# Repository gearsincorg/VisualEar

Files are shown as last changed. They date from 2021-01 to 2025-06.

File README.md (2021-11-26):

Visual Ear project
By Phil Malone
Phil.Malone@Mr-Phil.com
6/21/2021

https://hackaday.io/project/175944-the-visual-ear 
 
 This project is an experiment in audio perception.
 My goal was to produce a visual display that might help a deaf person experience sound.
 I got excited when I imagined what an orchestral performance might look like if each musician had such a display above their head.
 
 I started thinking about this project when I discovered that our Cochlea (the sensing part of our inner ear) does not just contain "hairs" that turn vibrations into electrical signals. 
 Instead, it is comprised of many micro structures (containing hairs) which are located along a tapered structure that filters out increasing frequencies of sound as you move into the structure.
 So, in reality, each successive cluster of hairs is detecting higher frequency components. 
 
 Thus the Cochlea does not convert vibrations into electrical impulses, but instead, it converts audio frequencies into electrical impulses.  It's acting as a spectrum analyzer.
 This is a marvelous piece of evolutionary adaption which removed the requirement of the brain to sense signals that were changing many thousands of times a second.
 
 This was quite a revelation to me, and it made me wonder if an external device that converted sound waves into similar frequency bands, and then displayed these bands using light (color and intensity) could be a crude substitute for a Cochlea.

 My first instinct was to think of a spectrum analyzer display that you might see on a high-end audio amplifier.
 There is nothing new about visual audio-spectrum displays, but I decided that it would be important to provide MUCH finer spectral resolution, while still maintaining near real-time response.

Display Specs:

- Display Bands:  104 Bands, spanning 43 Hz - 16744 Hz (8.5 Octaves, 12 LED's per octave)
- Intensity Range: Each Band is displayed with a secific color, and 255 intensity levels
- Display Update interval: 11.6 mSec (86 Hz)
- Audio to Visual Latency:  Max 13.5 mSec (11.6 mSec acquisition + 1.9 mSec for dual FFT & display)
- Visual Persistance:  Low Frequency (< 440 Hz) 185 mSec.  High Frequency (>= 440 Hz) 46 mSec.

 ** HOW IT WORKS 
 
 Note:  Program constants are referenced in this description as follows:  64 (CONSTANT_NAME)
 
 The Teensy audio library is used to sample the I2S digital microphone continuously at the standard 44100 Hz rate.  Successive Bursts of 128 samples are cataloged and saved as an array of Burst pointers.  This array holds 72 (NUM_BURSTS) Burst pointers.  Only 64 (BURSTS_PER_AUDIO) of these are being processed at any time.  The remaining 8 (EXTRA_BURSTS) are used to start capturing more audio while the current Packet of 64 Bursts is processed.  
 
 To cover the full 55-17,153 Hz spectrum, it’s necessary to aquire 8192 samples (64 Bursts of 128 samples).  But this would take 185 mSec to collect, so it’s not practical to wait for the full sample to be collected before updating the display.  
 
 To permit faster display updates, a sliding window is created to process the most recent 64 Bursts, every time a new set of 4 (BURSTS_PER_FFT_UPDATE) Bursts have been received.  This event occurs every 11.6 mSec, which becomes the update rate for the overall display (86 updates per second).
 
 A standard FFT (Fast Fourier Transform) is used to convert the Audio Packet (8196 Samples) into frequency buckets.  Initially, a single FFT was used to process the entire sample.  This transform could be performed in the available 11.6 mSec, but a high frequency sound spike would be spread over the entire 185 mS sample duration.  So a sudden sound would appear quickly, but it would persist on the display for the full 185 mSec.  This effectively limits the responsiveness of the system to rapid sounds like a drum roll.
 
 To accommodate BOTH slow low-frequency sounds, and rapid high-frequency sounds, the available Audio packet is processed by two separate FFTs.  Each optimized for a different frequency range.  The Low FFT is looking for sounds in the 55-880 Hz range.   The High FFT is looking for sounds in the 880-17,153 Hz range.  
 
 To capture and resolve low sounds, the Low FFT uses the entire Audio Packet, but it only processes every fourth sample.  This enables the FFT to work with a smaller input sample set of 2048, which still produces 1024 frequency bins of 5.4Hz width.
 
 To capture and resolve rapid high sounds, the High-FFT only uses the most recent quarter of the Audio Packet, but at the full 44.1 kHz sample rate.  This enables this FFT to also work with a smaller input sample set of 2048, but produces 1024 frequency bins of 21.5Hz width.  Since this FFT is only using a quarter of the sample history, short-pulse sounds only persist for a max of 46.4 mSec, which should be able to display a 10 Hz drum-roll.
 
CREDITS:

 > A lot of what I developed here was influenced strongly by Steve Marley https://github.com/s-marley/ESP32_FFT_VU
 
 > An explanation of the Spreadsheet used to determine the Band Bins is found here: https://www.youtube.com/watch?v=Mgh2WblO5_c
 
 > This project adapts the FFT library found here : https://github.com/kosme/arduinoFFT

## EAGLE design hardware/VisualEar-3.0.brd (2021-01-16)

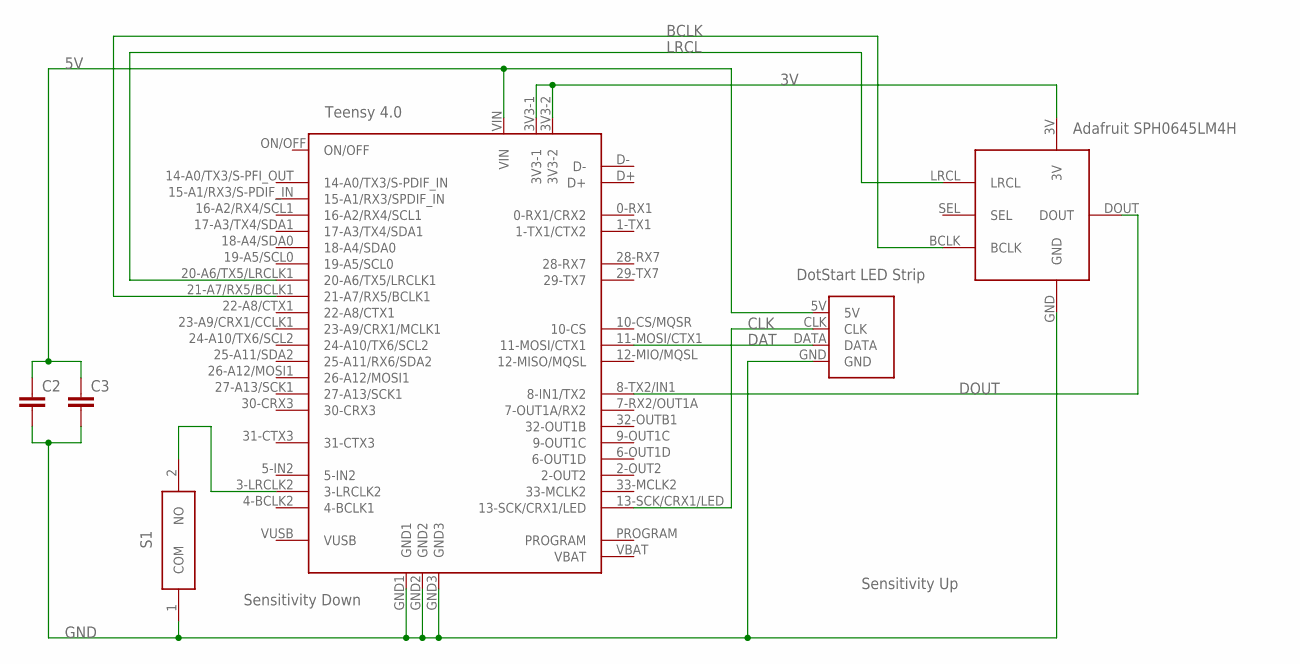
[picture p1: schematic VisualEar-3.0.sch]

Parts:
C2, C3: CAPPTH3; CAP-PTH-LARGE
S1: TACTILE-SWITCHTHRU-HOLE; CLICK-WEL
U$1: TEENSY40DIPPLUS5; TEENSY40-DIP+5
U$3: AF-I2S-MIC
U$4: LED-STRIP; LED_STRIP

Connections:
3V: U$1.3V3-1, U$1.3V3-2, U$3.3V
5V: C2.1, C3.1, U$1.VIN, U$4.5V
BCLK: U$1.21-A7/RX5/BCLK1, U$3.BCLK
CLK: U$1.13-SCK/CRX1/LED, U$4.CLK
DAT: U$1.11-MOSI/CTX1, U$4.DATA
DOUT: U$1.8-TX2/IN1 (8-IN1/TX2), U$3.DOUT
GND: C2.2, C3.2, S1.1 (COM), U$1.GND1, U$1.GND2, U$1.GND3, U$3.GND, U$4.GND
LRCL: U$1.20-A6/TX5/LRCLK1, U$3.LRCL
unnamed: S1.2 (NO), U$1.3-LRCLK2

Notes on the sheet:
DotStart LED Strip
Adafruit SPH0645LM4H
Teensy 4.0
Sensitivity Down
Sensitivity Up

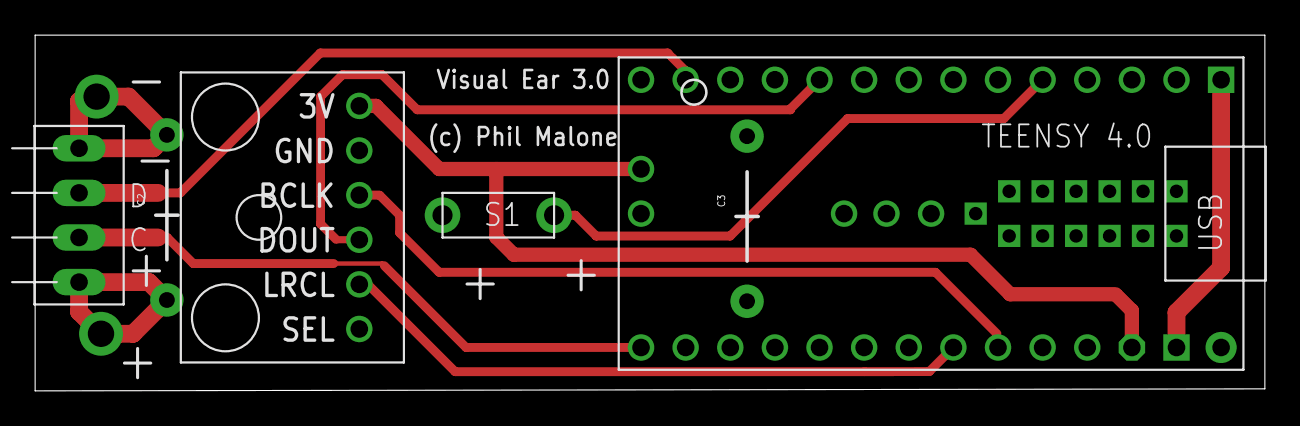
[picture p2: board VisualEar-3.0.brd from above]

Board: 2 copper layers, 70.0 x 20.2 mm, 6 parts (0 on the bottom side), 9 nets.

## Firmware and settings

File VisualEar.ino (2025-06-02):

/*
  Visual Ear
  Audio spectrum analyser
  LED strip display.
  For details see:  https://hackaday.io/project/175944-the-visual-ear
  Copyright (C) 2021-5 Philip Malone

  Display Modes:
  0 - Off
  1 - VU Mater
  2 - Specturm Analyser
  3 - Tone Detector
  4 - Fireworks
  5 - Ocean

  Version Date      Description
  2.0     2/2/2022  First release with 4 functions and 104 LEDs
  3.0     6/1/2025  Added Ocean mode with bubbles.
  
*/

#include  <Audio.h>
#include  <Wire.h>
#include  <SPI.h>
#include  <SerialFlash.h>
#include  <EEPROM.h>
#include  "audioAnalyzer.h"
#include  "devconf.h"
#include  "display.h"

#define  FASTLED_INTERNAL
#include "FastLED.h"

// Set project identification here
const char  Version[] = "Visual Ear. V4.0";
const char  Branch[]  = "Add Ocean";
const char  Description[]  = "104 Bands.  43Hz to 16744 Hz";
const char  Modes[]  = "(0) Off, (1) VU, (2) Spectrum, (3) Tone, (4) Fireworks, (5) Ocean";

// -- LED Display Constants
#define START_NOISE_FLOOR   60  // Frequency Bin Magnitudes below this value will not get summed into Bands. (Initial high value)  was 80
#define BASE_NOISE_FLOOR    40  // Frequency Bin Magnitudes below this value will not get summed into Bands. (Final minimumm value)

#define UI_HOLD_MS      3000
#define UI_STEP_MS       200
#define UI_BUTTON_PIN      3

const int myInput = AUDIO_INPUT_LINEIN;
//const int myInput = AUDIO_INPUT_MIC;

float     upGainAccumulator   = 0;
float     downGainAccumulator = 0;

// -- LED Display Data
uint32_t  bandValues[NUM_BANDS];
uint16_t  LO_bandBins[NUM_LO_BANDS + 1] = {13,14,15,16,17,18,20,21,22,23,25,26,28,29,31,33,35,37,39,41,44,46,49,52,55,58};
uint16_t  MD_bandBins[NUM_MD_BANDS + 1] = {29,31,33,35,37,39,41,44,46,49,52,55,58,62,66,70,74,78,83,88,93,98,104,110,117,124,131,139,147,156,165,175};
uint16_t  HI_bandBins[NUM_HI_BANDS + 1] = {25,27,28,30,32,33,35,37,40,42,45,47,50,53,56,60,63,67,71,75,79,84,89,94,100,106,112,119,126,134,142,150,159,168,178,189,200,212,225,238,252,267,283,300,318,337,357,378,400};

// Create the Audio components.  These should be created in the
AudioInputI2S          audioInput;     // audio shield: mic or line-in
AudioAnalyzeFFT        myFFT;
AudioAnalyzePeak       peak;          //xy=393,385

// Connect the live input
AudioConnection patchCord1(audioInput, 0, myFFT, 0);
AudioConnection patchCord2(audioInput, 0, peak, 0);

unsigned long startTime = millis();
unsigned long lastTime = millis();
unsigned long cycleTime = 0;

unsigned long buttonStart = 0;
bool          adjusting   = false;
bool          UIHolding = false;      
bool          UIButton  = false;      
bool          lastUIButton  = false;      

int           activeBands = 0;

// Non Volatile values
short         gainNumber  = 0;

// ==================================================================================================

void setup() {
  Serial.begin(500000); 

  pinMode(UI_BUTTON_PIN, INPUT_PULLUP);

  // Audio connections require memory to work.  For more
  AudioMemory(NUM_BURSTS);

  // read NV Ram
  setDisplayMode( EEPROM.read(MODE_ADDRESS));
  setGain(EEPROM.read(GAIN_ADDRESS));
  Serial.println(Version);
  Serial.println(Branch);
  Serial.println(Description);
  Serial.println(Modes);
  delay(100);

  initDisplay();
}

void loop() {
  // check the button and see if we have a change
  runUI();

  if (getDisplayMode() == 1) {       
    if (peak.available()){
      updateVuDisplay(peak.readPeakToPeak());
    }
  } else {       
    if (myFFT.available()) {
      // each time new FFT data is available update the diplay
      startTime = millis();
      cycleTime = startTime - lastTime;
      lastTime = startTime;
  
      fillBands();
      updateDisplay(bandValues);
      runAGC();
    }
  }
}

// ==================================================================================================

void  runUI() {
  
  // debounce
  if (pressElapsed() > 100) {
    UIButton = !digitalRead(UI_BUTTON_PIN);

    //  Just Pressed, start the hold timer
    if (UIButton && !lastUIButton) {
      pressReset();
    }

    // Look for button release.  Bump mode
    if (!UIButton && lastUIButton) {
      if (!UIHolding) {
        bumpMode();
      }
    }

    lastUIButton = UIButton;
  }
}

long  pressElapsed() {
  return millis() - buttonStart;
}

void  pressReset() {
  buttonStart = millis() ;
}

void  runAGC(){
  // Automatic Gain Control
    // Automatically control the gain to keep a reasonable quantity of active frequency buckets
  
  float OCR = (float)activeBands / (float)NUM_BANDS;
  
  /*
  Serial.print("AB ");
  Serial.print(activeBands);
  Serial.print(", GN ");
  Serial.println(gainNumber);
  */

  if (OCR < lowTrip) {
    upGainAccumulator += 0.01;
  } else if (OCR > highTrip) {
    upGainAccumulator -= 0.04;
  }

  if (upGainAccumulator > 1.0) {
    bumpGain(1);
    upGainAccumulator = 0.0;
  } else if (upGainAccumulator < -1.0) {
    bumpGain(-1);
    upGainAccumulator = 0.0;
  }

  /*  
  Serial.print("AGC OLC ");
  Serial.print(OLC);
  Serial.print(", OCR ");
  Serial.print(OCR);
  Serial.print(", UA ");
  Serial.print(upGainAccumulator);
  Serial.print(", Gain Number ");
  Serial.println(gainNumber);
  */
}

void  bumpGain(int step ) {
  buttonStart = millis();
  setGain(gainNumber + step);  
  pressReset();
}

void  bumpMode() {
  buttonStart = millis();
  EEPROM.write(MODE_ADDRESS, switchDisplayMode());
  initDisplay();  
}

// save the current selected gain value (which LED) and calculate Amplitude divide factor
int  setGain(short newgain) {
double        gainScale;

  if (newgain < MIN_GAIN_NUM)
    newgain = MIN_GAIN_NUM;
  else if (newgain > MAX_GAIN_NUM)
    newgain = MAX_GAIN_NUM;

  gainNumber = newgain;
  EEPROM.write(GAIN_ADDRESS, gainNumber);

  gainScale  = minScale * pow(gainSlope, gainNumber);
  myFFT.setInputScale(gainScale);

  /*
  Serial.print("Gain # ");
  Serial.print(gainNumber);
  Serial.print(" Gain ");
  Serial.println(gainScale * 100);
  */

  return gainNumber;
}

// ==================================================================================================

// Group Frequency Bins into Band Buckets based on the maximum nun number for each band
// Each band covers more bind because bins are linear and bands are logorithmic.
void  fillBands (void){
  uint32_t  noiseFloor;  
  uint8_t   band;   

  //  zero out all the LED band magnitudes.
  memset(bandValues, 0, sizeof(bandValues));

  // Cycle through each of the LED bands.  Set initial noise threshold high and drop down.
  noiseFloor = START_NOISE_FLOOR;
  band = 0;
  activeBands = 0;
    
  for (int b = 0; b < NUM_LO_BANDS; b++, band++){
    // Accumulate freq values from all bins that match this LED band,
    bandValues[band] = (uint32_t)myFFT.read(0, LO_bandBins[b], LO_bandBins[b+1], noiseFloor);
    if (bandValues[band] > 2)
      activeBands++;

    // Adjust Noise Floor
    if (noiseFloor > BASE_NOISE_FLOOR) {
      noiseFloor = 97 * noiseFloor / 100;  // equiv 0.97 factor.
    }
  }

  for (int b = 0; b < NUM_MD_BANDS; b++, band++){
    // Accumulate freq values from all bins that match this LED band,
    bandValues[band] = (uint32_t)myFFT.read(1, MD_bandBins[b], MD_bandBins[b+1], noiseFloor);
    if (bandValues[band] > 2)
      activeBands++;

    // Adjust Noise Floor
    if (noiseFloor > BASE_NOISE_FLOOR) {
      noiseFloor = 97 * noiseFloor / 100;  // equiv 0.97 factor.
    }
  }

  for (int b = 0; b < NUM_HI_BANDS; b++, band++){
    // Accumulate freq values from all bins that match this LED band,
    bandValues[band] = (uint32_t)myFFT.read(2, HI_bandBins[b], HI_bandBins[b+1], noiseFloor);
    if (bandValues[band] > 2)
      activeBands++;

    // Adjust Noise Floor
    if (noiseFloor > BASE_NOISE_FLOOR) {
      noiseFloor = 95 * noiseFloor / 100;  // equiv 0.95 factor.
    }
  }

}

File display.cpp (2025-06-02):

/*


*/

#include <Arduino.h>
#include "arm_math.h"
#include "devconf.h"
#include "display.h"

#define  FASTLED_INTERNAL
#include "FastLED.h"

// ======================================================================================================

CRGB      leds[NUM_LEDS];

float     hueStep;
int       numBands;
int       nextBall = 0;
uint32_t  lastMoveMs = 0;

float     pos[MAX_BALLS];
float     vel[MAX_BALLS];
uint8_t   band[MAX_BALLS];

uint8_t   numBalls[NUM_BANDS];
short     displayMode; 
uint32_t  modeChangeRelease = 0;

double    gainSlope = 1.0;
double    minScale  = 0.0;
double    lowTrip   = 0;
double    highTrip  = 1;

int       orangeLED;
int       redLED;

double  peakFilter = 0;
double  levelFilter = 0;

// ======================================================================================================
// Generic Display Functions
// ======================================================================================================
void  setDisplayMode(short  mode) {
  displayMode = mode;    
}

short  getDisplayMode() {
  return(displayMode);    
}

short  switchDisplayMode() {
  displayMode = (short)((displayMode + 1 ) % NUM_MODES);
  modeChangeRelease = millis() + MODE_CHANGE_PAUSE;
  showMode();
  return (displayMode);
}

void  initDisplay(){

  delay(250);      // sanity check delay
  FastLED.addLeds<APA102, BGR>(leds, NUM_LEDS);
  FastLED.clear();
  
  switch (displayMode) {
    default:
    case 0:   // Off
      break;

    case 1:  // VU Meter
      orangeLED   = (int)((ORANGE_DB - MIN_DB) / DB_PER_LED);
      redLED      = (int)((RED_DB    - MIN_DB) / DB_PER_LED);
      break;
      
    case 2:  // FFT
      initFFTDisplay(NUM_BANDS);

    case 3:  // Tone
      initFFTDisplay(NUM_BANDS);
      break;

    case 4:  //  Fireworks
      initBallDisplay(NUM_BANDS);
      break;

    case 5:  // Bubbles
      initBallDisplay(NUM_BANDS);
      break;
  }
}

void  updateDisplay(uint32_t * bandValues) {
  // display the data in the selected way.
  if (millis() > modeChangeRelease) {
    switch (displayMode) {
      default:
      case 0:  //Off
        break;
      
      case 2: // FFT
        updateFFTDisplay(bandValues);
        break;
  
      case 3: // TONE
        updateToneDisplay(bandValues);
        break;

      case 4:  // Fireworks
        updateBallDisplay(bandValues);
        break;
          
      case 5:  // Bubbles
        updateBallDisplay(bandValues);
        break;
          
    }
  }
}

// ======================================================================================================
// trajectory functions
// ======================================================================================================

// ======================================================================================================
//  Basic display functions
// ======================================================================================================
void  setLEDBand(int band,  int intensity) {
  setLED(band, (uint16_t)(band * hueStep), intensity);
}

int flipLEDs(int num) {
  return (NUM_LEDS - num - 1);
}

void  setLED(int pos, int hue, int intensity) {
  if (pos < NUM_LEDS) {
    if (FLIP_LED_ORDER){
      pos = flipLEDs(pos);
    } 
  
    leds[pos].setHSV(hue, 255, intensity);
  }
}

void  showMode () {
  FastLED.clearData();
  FastLED.show();
  for (int I = 0; I < displayMode; I++) {
    setLEDBand(I * 8, MAX_LED_BRIGHTNESS); 
  }
  FastLED.show();
}

// ======================================================================================================
//  FFT display functions
// ======================================================================================================

// Configure the LED string and preload the color values for each band.
void  initFFTDisplay(int numberBands) {

  const double MIN_GAIN_SCALE  = 0.00125;
  const double MAX_GAIN_SCALE  = 0.10; 
  const double LOW_TRIP        = 0.05; 
  const double HIGH_TRIP       = 0.25; // Was 0.3
  
  minScale  = MIN_GAIN_SCALE;   
  gainSlope = pow((MAX_GAIN_SCALE / MIN_GAIN_SCALE), 1.0 / MAX_GAIN_NUM);   
  lowTrip   = LOW_TRIP;
  highTrip  = HIGH_TRIP;
  
  numBands = numberBands;
  hueStep = TOP_HUE_NUMBER / numBands;   // How much the LED Hue changes for each step.
}

// Update the LED string based on the intensities of all the Frequency bins.
void  updateFFTDisplay (uint32_t * bandValues){
  uint16_t ledBrightness;
  
  // Process the LED buckets into LED Intensities
  for (byte band = 0; band < numBands; band++) {
    
    // Scale the bars for the display
    ledBrightness = bandValues[band];

    if (ledBrightness > MAX_LED_BRIGHTNESS)  {
      ledBrightness = MAX_LED_BRIGHTNESS;
    }
  
    // Display LED Band in the correct Hue.
    setLEDBand(band, ledBrightness);
  }
  
  // Update LED display
  FastLED.show();
}

// ======================================================================================================
//  Tone display functions
// ======================================================================================================

// Update the LED string based on the intensities of all the Frequency bins.
void  updateToneDisplay (uint32_t * bandValues){
  uint16_t ledBrightness = 0;
  uint16_t maxBand = -1;

  // Find the band with the strongets signal and light it up.
  for (byte band = 0; band < numBands; band++) {
    if (bandValues[band] > ledBrightness) {
      ledBrightness = bandValues[band];
      maxBand = band;
    }
  }
   
  if (ledBrightness > 0) {
    FastLED.clearData();
    // Display LED Band in the correct Hue.
    if (ledBrightness > MAX_LED_BRIGHTNESS)  {
      ledBrightness = MAX_LED_BRIGHTNESS;
    }

    // Update LED display
    setLEDBand(maxBand, ledBrightness);
    FastLED.show();
  }
}


// ======================================================================================================
//  Air Balls display functions
// ======================================================================================================

// Configure the LED string and preload the color values for each band.
void  initBallDisplay(int numberBands) {
  numBands = numberBands;
  hueStep = TOP_HUE_NUMBER / numBands;   // How much the LED Hue changes for each step.

  const double MIN_GAIN_SCALE  = 0.001;
  const double MAX_GAIN_SCALE  = 0.05;
  const double LOW_TRIP        = 0.04; 
  const double HIGH_TRIP       = 0.30; // Was 0.35
  
  minScale  = MIN_GAIN_SCALE;   
  gainSlope = pow((MAX_GAIN_SCALE / MIN_GAIN_SCALE), 1.0 / MAX_GAIN_NUM);   
  lowTrip   = LOW_TRIP;
  highTrip  = HIGH_TRIP;

  // initialize ball data;
  memset(pos, 0, sizeof(pos));
  memset(vel, 0, sizeof(vel));
  memset(band, 0, sizeof(band));
  memset(numBalls, 0, sizeof(numBalls));
}
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

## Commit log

2020-12-16 Upgrade to optimal buffering
    [FFT-Band-Bin calculator.xlsx]
2021-01-03 Split FFT working
    [FFT-Band-Bin calculator.xlsx]
2021-01-16 Added PCB files for Rev 2.0
    [VisualEar-2.0.brd, VisualEar-2.0.sch]
2021-01-16 Updated to Single Button 3.0 PCB
    [VisualEar-3.0.brd, VisualEar-3.0.sch]
2021-01-19 REV 3.0 updates
    Reverted back to 59 LEDs .
    Single button gain control.
    Click up, Hold Down
    [VisualEar.ino]
2021-02-08 Added variable sample rate
    [FFT-Band-Bin calculator-x80.xlsx, FFT-Band-Bin calculator.xlsx]
2021-02-10 104 band release
    [FFT-Band-Bin calculator-x80.xlsx]
2021-02-18 Flipped LED order for Inverted display
    [VisualEar.ino]
2021-08-12 139 LED tri-band
2021-11-26 137 band update-
    [FFT-Band-Bin calculator-108B-9x12.xlsx, FFT-Band-Bin calculator-x104.xlsx, FFT-Band-Bin calculator-x137.xlsx]
2021-11-26 Changed to 104 bands (12 bands per octave)
    [FFT-Band-Bin calculator-108B-9x12.xlsx]
2022-01-18 Added new pitch Mode
    [FFT-Band-Bin calculator-96-8x12.xlsx]
